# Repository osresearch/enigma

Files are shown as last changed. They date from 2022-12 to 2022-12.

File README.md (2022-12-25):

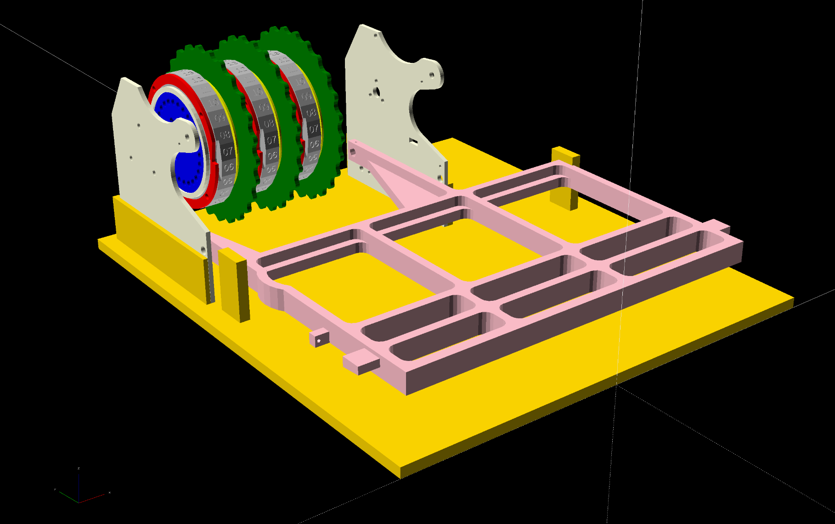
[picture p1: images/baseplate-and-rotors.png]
baseplate and rotors rendered in openscad


# 3D printable enigma machine

Based on the blue prints from [Enigma Nachbauprojekt](http://www.enigma.hs-weingarten.de/drawings.php)

The full size machine won't fit on a Mini printer and there are several parts
that are not easily FDM printable.  The `printable.scad` has modifications from
the original design to make it easier to print.

**NOTE** This is a work in progress! Some of the parts have been test printed,
but not all of the designs are ready yet.

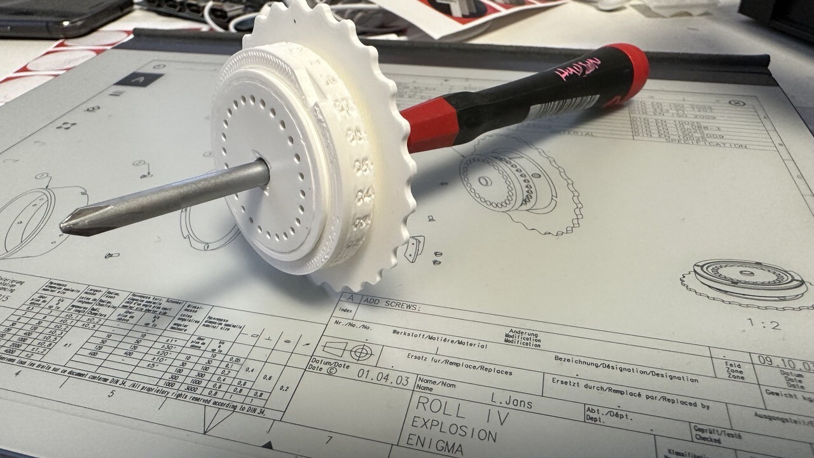
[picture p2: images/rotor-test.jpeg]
initial rotor test


Hardware:

* M3 counter sink screws
* M5 axle for rotor
* Need to find pogopins and pogopads

Ideas:

* Use a PCB for the rotor plate? This would allow the wiring to be done in the circuit.
* Laser cut some parts?

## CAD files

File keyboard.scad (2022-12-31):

// keyboard from the rack pdf
include <util.scad>

// 100021 pillar small
pillar_small_len = 31;
module pillar_small()
{
	render() difference()
	{
		cylinder(d=6, h=pillar_small_len, $fn=32);

		// tap both sides
		mirror_dupe([0,0,1], center=[0,0,pillar_small_len/2]) 
		drill(3, 8, tap=true);
	}
}

// 100019
column_short_len = 75.7;
column_long_len = 92.7;
module column_short()
{
	render() difference()
	{
		cylinder(d=7, h=column_short_len, $fn=32);

		// tap both sides
		mirror_dupe([0,0,1], center=[0,0,column_short_len/2]) 
		drill(4, 10, tap=true);
	}
}

// column long 100017 7mm x 92.7 with cross drilled m3 at 18mm
module column_long()
{
	render() difference()
	{
		cylinder(d=7, h=column_long_len, $fn=32);

		// tap both sides
		mirror_dupe([0,0,1], center=[0,0,column_long_len/2]) 
		drill(4, 10, tap=true);

		// cross drill
		translate([0,-5,column_long_len - 18])
		rotate([-90,0,0])
		drill(3, 10, tap=true);
	}
}

// input board 100018
// held up by column short 100019 7mm x 75.7
// and column long 100017 7mm x 92.7 with cross drilled m3 at 18mm


// there are fancy curves that we are ignoring for now
// the input board is also supposed to be bent metal, so it is "hollow"
// while this one is solid
input_board_w = 257;
input_board_h = 82;

module input_board_base()
{
if(0) {
	box(input_board_w, input_board_h, 10.7,
		pos=[0,input_board_h,0], ref="c-+");

	box(input_board_w, input_board_h - 39.5, 19.2-10.7,
		pos=[0,input_board_h,10.7], ref="c-+");

	box(input_board_w, input_board_h - 60.5, 27.7 - 19.2,
		pos=[0,input_board_h,19.2], ref="c-+");
}

	// rotate and align so that top of the top shelf is at 27.7mm
	translate([-input_board_w/2,0,27.7 + 2.43])
	rotate([0,90,0]) linear_extrude(height=input_board_w) import("inputboard.svg");
}

module input_board()
{
	key_d = 6.2 + 1;

	translate([0,-46.25+8.5,0])
	render() difference()
	{
		input_board_base();

		// keys
		for(i=[0:8]) {
			translate([input_board_w/2 - 26.5 - i*24.2,68.5,-1])
			cylinder(d=key_d, h=100);
		}

		for(i=[0:7]) {
			translate([input_board_w/2 - 43.8 - i*24.2,46.5,-1])
			cylinder(d=key_d, h=100);
		}

		for(i=[0:8]) {
			translate([input_board_w/2 - 36.9 - i*24.2,24.0,-1])
			cylinder(d=key_d, h=100);
		}

		// top row mounting screws
		mirror_dupe()
		drill(M25, 5, pos=[226/2, 68.5, 27.7-5], countersink=true, dir=-1);

		// bottom row mounting screws
		mirror_dupe()
		drill(M25, 5, pos=[226/2, 24.0, 10.7-5], countersink=true, dir=-1);

		// center row mounting screw
		drill(M25, 5, pos=[ 0, 46.25, 19.2-5], countersink=true, dir=-1);

		// fake the hollow body with large holes for the shafts
		if(0) {
		mirror_dupe()
		drill(10, 27.7-2, pos=[226/2, 68.5]);
		mirror_dupe()
		drill(10, 10.7-2, pos=[226/2, 24.5]);
		drill(10, 19.2-2, pos=[ 0, 46.25]);
		}

		// front mounting holes
	}
}


// 100020
module contactor_plate()
{
	contactor_plate_w = 243;
	contactor_plate_h = 56;
	contactor_plate_thick = 2;

	translate([0,8.2,0])
	render() difference()
	{
		box(contactor_plate_w, contactor_plate_h, contactor_plate_thick, ref="cc+");

		// rounded cutouts on the edge
		mirror_dupe()
		translate([contactor_plate_w/2, 0,-1])
		box(30,13,3, r=5, ref="cc+");

		// pass through for upper input board columns,slightly oversized
		quad_dupe()
		translate([226/2, 44.5/2, -1])
		cylinder(d=7+0.5, h=contactor_plate_thick+2, $fn=32);

		// top row drills
		for(i=[0:8])
			translate([-91.6+24.2*i,44.5/2,-1])
			{
				cylinder(d=6.2, $fn=24, h=contactor_plate_thick+2);
				mirror_dupe()
				translate([6.6,-4.6,0]) cylinder(d=2, h=contactor_plate_thick+2, $fn=16);
			}

		// middle row drills
		for(i=[0:7])
			translate([-85+24.2*i,0/2,-1])
			{
				cylinder(d=6.2, $fn=24, h=contactor_plate_thick+2);
				mirror_dupe()
				translate([6.6,-4.6,0]) cylinder(d=2, h=contactor_plate_thick+2, $fn=16);
			}

		// bottom row drills
		for(i=[0:8])
			translate([-102+24.2*i,-44.5/2,-1])
			{
				cylinder(d=6.2, $fn=24, h=contactor_plate_thick+2);
				mirror_dupe()
				translate([5.5,+4.6,0]) cylinder(d=2, h=contactor_plate_thick+2, $fn=16);
			}

		// some random drills
		translate([4,-8.2,-1]) cylinder(d=4.2, h=contactor_plate_thick+2, $fn=16);
		translate([0,0,-1]) cylinder(d=4.2, h=contactor_plate_thick+2, $fn=16);

		// label to make the top side obvious
		translate([0,5,contactor_plate_thick-1])
		linear_extrude(height=2) text("TOP", size=5);
	}
}

// derived from the three buttons, includes keycap
module _button_template(k, h=64, mids=[37], include_button=1)
{
	render() difference()
	{
		cylinder(d=6, h=h, $fn=60);

		// slat and pins at the top if we are not including the button
		if (!include_button)
		{
			translate([0,0,h+0.1])
			box(10, 2, 10+0.1, ref="cc-");

			translate([0,5,h-2.5]) rotate([90,0,0]) drill(1, 10);
			translate([0,5,h-7.5]) rotate([90,0,0]) drill(1, 10);
		}

		// small flat on both side with M3 through it
		for(mid=mids) {
			translate([0,0,mid])
			{
				mirror_dupe()
				box(5,3,8, ref="+cc", pos=[5/2,0,0]);

				rotate([0,90,0]) cylinder(d=3, h=10, center=true, $fn=30);
			}
		}

		// big flat on one side
		translate([1.5,0,5])
		box(5,5,27-5, ref="+c+");

		// and recessed thingy in the bottom
		drill(3, 1.5);
		translate([0,0,1]) cylinder(d1=4, d2=3, h=1.5, $fn=30);
	}

	if (include_button)
	render() difference() {
		translate([0,0,h])
		cylinder(d=12, h=2, $fn=60);

		translate([0,0,h+1])
		linear_extrude(height=2) text(str(k), size=8, valign="center", halign="center");
	}
}

module button_short(k) { _button_template(k, 64, [37]); }
module button_medium(k) { _button_template(k, 72.5, [29]); }
module button_long(k) { _button_template(k, 81, [20, 29]); }


top_keys = "QWERTZUIO";
mid_keys = "ASDFGHJK";
bot_keys = "PYXCVBNML";

module keyboard_assembly()
{
translate([0,40,baseplate_thick + pillar_small_len]) contactor_plate();
translate([0,40,baseplate_thick + column_short_len - (10.7-2)])
{
	//color("yellow")
	input_board();

	color("silver")
	translate([0,8.5,-45])
	{
		// top row keys
		for(i=[0:8])
			translate([-91.6+24.2*i,44.5/2,-1])
			button_long(top_keys[i]);

		// middle row
		for(i=[0:7])
			translate([-85+24.2*i,0/2,-1])
			button_medium(mid_keys[i]);

		// bottom  row
		for(i=[0:8])
			translate([-102+24.2*i,-44.5/2,-1])
			button_short(bot_keys[i]);
	}
}


// this might not be right
translate([   4.0,  40.0, baseplate_thick]) pillar_small();

mirror_dupe()
{
// not shown -- column center high
translate([-226/2,70.5,baseplate_thick]) column_long();
translate([-226/2,26.0,baseplate_thick]) column_short();
}
}

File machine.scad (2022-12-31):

/*
 * An assembled machine for display, not printing
 */
printable=true;

include <rotor.scad>
include <rack.scad>
include <keyboard.scad>
include <lamp.scad>

if (1) {
baseplate(printable=printable);

translate(compensator_pos)
rotate([5,0,0])
compensator_assembly();

translate(bearingblock_pos)
translate([-bearingblock_t,(55.5-48.5)/2 - 4/2,22 - 9.5])
rotate([90,0,90])
bearing_assembly(printable=printable);

keyboard_assembly();
lamp_assembly();

} else scale(0.5) {
/*
	translate([0,0,6]) compensator();
	translate([180,-40,0]) access_roll_housing();
	translate([20,20,0]) bearing_block_left();
	translate([150,20,0]) bearing_block_right();
	translate([40, -50,0]) shaft_holder();
*/
//%rotate([0,0,-60]) reflector_cabinet();
reflector_wedge_holder();
}

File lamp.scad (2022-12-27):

// lamp stuff from the rack pdf
include <util.scad>


// 10022
module segment_plate()
{
	segment_plate_w = 218;
	segment_plate_h = 46;
	segment_plate_thick = 2;

	bottom_drill = -segment_plate_h/2 + 3.5;
	top_drill = -segment_plate_h/2 + 42;

	render() difference()
	{
		box(segment_plate_w, segment_plate_h, segment_plate_thick, ref="c++");

		// random drills
		drill(4.2, segment_plate_thick, coords=[
			[  0.0, 23],
			[-95.0, 4.0],
			[-65.5, 4.0],
			[  5.5, 4.0],
			[ 78.5, 4.0],
			[ 96.5, 4.0],
			[-81.5, 42],
			[+66.5, 42],
		]);

		// notched edges
		mirror_dupe()
		translate([segment_plate_w/2-5,29,-1])
		cube([50,50,segment_plate_thick+2]);

		// triple hole pattern at the bottom
		for(i=[0:8])
			translate([-segment_plate_w/2 + 6 + i*24.2, +3.5, 0])
			drill(2, segment_plate_thick, tap=true, coords=[
				[0,0],
				[0,5],
				[0,10],
			]);

		// triple hole pattern at the top
		for(i=[0:8])
			translate([-segment_plate_w/2 + 16.4 + i*24.2, +31.5, 0])
			drill(2, segment_plate_thick, tap=true, coords=[
				[0,0],
				[0,5],
				[0,10],
			]);
		for(i=[0:7])
			translate([-segment_plate_w/2 + 23.3 + i*24.2, +28.0, 0])
			drill(2, segment_plate_thick, tap=true, coords=[
				[0,0],
				[0,5],
				[0,10],
			]);
	}

	// side plates
	mirror_dupe()
	translate([-segment_plate_w/2,0,0])
	render()  difference()
	{
		box(2,29,14, ref="+++");
		mirror([1,0,0]) rotate([0,-90,0])
		{
			drill(6, 2, [5,18]);
			drill(3, 2, tap=true, coords=[
				[10,5],
				[10,24],
			]);
		}
	}
}


// 100050
// this is supposed to be made from bent sheet metal, so it isn't exactly right
module lamp_holder()
{
	lamp_holder_w = 226;

	render() difference() {
		box(lamp_holder_w, 60, 2, ref="cc+");
		countersink(5, 2, reverse=true);

		for(i=[0:7])
			drill(9.3, 2, pos=[lamp_holder_w/2-29-i*24, 0]);
		for(i=[0:8])
			drill(9.3, 2, pos=[lamp_holder_w/2-19-i*24, +40/2]);
		for(i=[0:8])
			drill(9.3, 2, pos=[lamp_holder_w/2-22-i*24, -40/2]);
	}

	mirror_dupe()
	translate([lamp_holder_w/2,0,2])
	rotate([0,90,0])
	render() difference()
	{
		hull() {
			box(1,1,2, pos=[0,+60/2,0], ref="+-+");
			box(1,1,2, pos=[0,-60/2,0], ref="+++");
			box(1,1,2, pos=[30,+60/2,0], ref="+-+");
			box(1,1,2, pos=[30,-60/2,0], ref="+++");
			box(1,1,2, pos=[51,+29/2,0], ref="--+");
			box(1,1,2, pos=[51,-29/2,0], ref="-++");
		}

		dupe([
			[51-33, +40/2],
			[51-33,  0],
			[51-33, -40/2],
			[51- 6, -19/2],
			[51- 6, +19/2],
		])
		drill(3.2, 2);
	}
}


// merged socket bar 100061 and L section 100060
module socket_bar()
{
	socket_bar_w = 223;
	socket_bar_h = 55;
	socket_bar_t = 4;

	render() difference()
	{
		box(socket_bar_w, socket_bar_h, socket_bar_t, ref="cc+");

		dupe([
			[-214/2, -40/2],
			[-214/2, +40/2],
			[+214/2, -40/2],
			[+214/2, +40/2],
			[-214/2, 0],
			[-144/2, 0],
  			[     0, 0],
			[+144/2, 0],
			[+214/2, 0],
		]);
			drill(3.2, socket_bar_t);

		for(i=[0:8])
			drill(3, socket_bar_t, pos=[socket_bar_w/2 - 10.5 - 24*i, 40/2]);
		for(i=[0:7])
			drill(3, socket_bar_t, pos=[socket_bar_w/2 - 27.5 - 24*i, 0]);
		for(i=[0:8])
			drill(3, socket_bar_t, pos=[socket_bar_w/2 - 20.5 - 24*i, -40/2]);
	}

	// L-section
	mirror_dupe()
	translate([socket_bar_w/2,0,0])
	render() difference()
	{
		box(3, socket_bar_h, 8, ref="+c+");
		rotate([90,0,90])
		dupe([
			[-20,4.5],
			[  0,4.5],
			[+20,4.5],
		])
		drill(3, 18, tap=true);
	}
}

// stack up of:
// isolator plate 100062
// lamp holder
// socket bar 100061 + L section 100060
// flanges
// segment plate
module lamp_assembly()
{
dupe([
	[  -3.5, 114.5],
	[-100.0, 133.5],
	[ +91.5, 133.5],
	[ -70.0, 95.5 ],
	[ +78.0, 95.5 ],
], z=baseplate_thick)
	pillar_small();
	
translate([-3.5,114.5, baseplate_thick + pillar_small_len])
{
	rotate([0,0,180]) // spin it around
	translate([0,-23,0]) // center on the center screw
	segment_plate();

	translate([0,8.5,33]) socket_bar();

	translate([0,8.5,53.5]) lamp_holder();
}

}

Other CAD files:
printable.scad
rack.scad
rotor.scad
test-cube.scad
util.scad

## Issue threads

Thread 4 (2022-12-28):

Bearing plate holes need counter sinks

osresearch, 2022-12-28:
The SVG outline doesn't counter sink the access cup

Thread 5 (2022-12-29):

baseplate mounts for bearing blocks are in the wrong place?

osresearch, 2022-12-29:
there is almost zero clearance on right side of the compensator

osresearch, 2022-12-29:
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

they were in the wrong place and the right place is *worse*. the real one shows how tight that clearance is

Closed 2022-12-29.

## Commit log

2022-12-24 enigma rotor progress
    [rotor.scad]
2022-12-24 bushing and toothed wheel engagement notch
    [rotor.scad]
2022-12-24 rotor is mostly complete
    [rotor.scad]
2022-12-24 animated rotor
    [rotor.scad]
2022-12-25 started on rack designs
    [machine.scad, rack.scad, rotor.scad]
2022-12-25 printable version of things
    [printable.scad, rack.scad, rotor.scad]
2022-12-25 compensator rack done?
    [rack.scad]
2022-12-25 bearing block outlines from svg
    [rack.scad]
2022-12-25 with base plate started and posed
    [rack.scad]
2022-12-25 ignore stl
2022-12-25 fix spacing on digit ring
    [rotor.scad]
2022-12-25 pawl stops, centering spring holders
    [rack.scad]
2022-12-26 tweak positions, add reverse countersink, separate assembled machine into its own file
    [machine.scad, rack.scad, rotor.scad]
2022-12-26 lots of baseplate screw holes
    [rack.scad]
2022-12-26 split util functions out, start on generic box() function
    [rack.scad, rotor.scad, util.scad]
2022-12-26 spin util
    [util.scad]
2022-12-26 pre-scale machine for printing
    [machine.scad]
2022-12-26 access roll and use spin util
    [rack.scad, rotor.scad]
2022-12-26 access roll and reflector
    [rack.scad, rotor.scad]
2022-12-26 started on input board
    [keyboard.scad, machine.scad]
2022-12-27 mirror_dupe center, quad_dupe, drill, and dupe
    [util.scad]
2022-12-27 started on keyboard and lamp assemblies
    [keyboard.scad, machine.scad]
2022-12-27 spin phase, drill mirror
    [util.scad]
2022-12-27 shaft holder
    [rack.scad, rotor.scad]
2022-12-27 lever for removing the rollers
    [rack.scad]
2022-12-27 Key caps!
    [keyboard.scad]
2022-12-27 split lamp into separate file
    [keyboard.scad, lamp.scad, machine.scad]
2022-12-27 lamp socket holder
    [lamp.scad]
2022-12-27 printable hacks
    [machine.scad]
2022-12-27 roll shaft
    [rack.scad, rotor.scad]
2022-12-27 printability fixes for more rotor tests
    [printable.scad, rotor.scad]
2022-12-28 specify screw sizes and do some tiny tap offsets (#1)
    [util.scad]
2022-12-28 compensator screw and clearance fixes (#2)
    [rack.scad]
2022-12-28 use defined screw sizes for access roll housing
    [rotor.scad]
2022-12-28 countersink: make it more sinky
    [util.scad]
2022-12-28 shaft holder: increase spacing
    [rotor.scad]
2022-12-28 bearing block: add holes at precise positions
    [rack.scad]
2022-12-28 calibration cube for drill and tap offsets
    [test-cube.scad]
2022-12-28 tweak countersink size and drill offsets
    [test-cube.scad, util.scad]
2022-12-29 fix countersink angle, update drill offset sizes, add round_keyway
    [util.scad]
2022-12-29 printable centering wheel and merged digit ring
    [printable.scad]
2022-12-29 lots of small tweaks on printability and started on the wedge
    [machine.scad, rack.scad, rotor.scad]
2022-12-31 lots of little hacks on the centering devices and advance pawls. mostly works!
    [printable.scad, rack.scad, util.scad]
2022-12-31 merged baseplate and bearings for printable version
    [machine.scad, printable.scad, rack.scad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]
2022-12-31 use input board outline from pdf
    [keyboard.scad]
